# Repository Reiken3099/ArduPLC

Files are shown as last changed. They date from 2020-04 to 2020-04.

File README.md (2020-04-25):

# ArduPLC

PCB board designs developed with the purpose of being used as an alternative to the widely known PLCs in industrial environments, focusing on keeping these PCB boards as closely attached to what is currently used in the industry in terms of voltages and currents. This project does not seek in any way to replace the use of PLC devices in the industry or any related element, it is developed with the sole purpose of having a reliable and low-cost alternative to such devices, mainly for small or micro companies that require a considerable degree of automation keeping your costs and expenses as low as possible.

These boards base their operation on the ATMEL microcontrollers used in the Arduino boards, for which these can be programmed in a simple and intuitive way using the Arduino IDE software, loading the bootloader of the corresponding Arduino boards in these microcontrollers, or failing that as well They can be programmed using assembly language or C ++ and programmed with the help of a microcontroller recorder or charger. Any PCB board shown here was designed to be used with the Arduino bootloader, since by including this, you can use the program free software called "LDmicro", through which you can program ATMEL microcontrollers with the Arduino bootloader using the LADDER language or also known as the ladder language, the same language that is used to program PLC devices today.

This is a project that is currently under development, so the plates shown here have not yet been polished in terms of design and structure of their components, however, each one is fully functional and has been physically and different simulations.

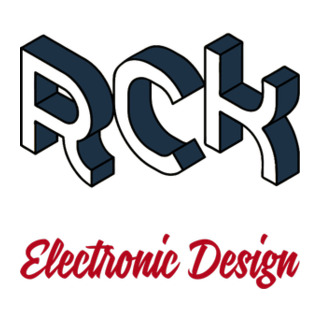
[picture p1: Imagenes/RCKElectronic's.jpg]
Logo of the organization RCKElectronic's
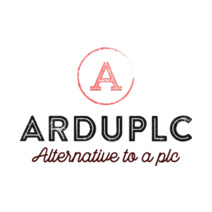
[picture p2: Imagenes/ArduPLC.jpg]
Logo of the proyect


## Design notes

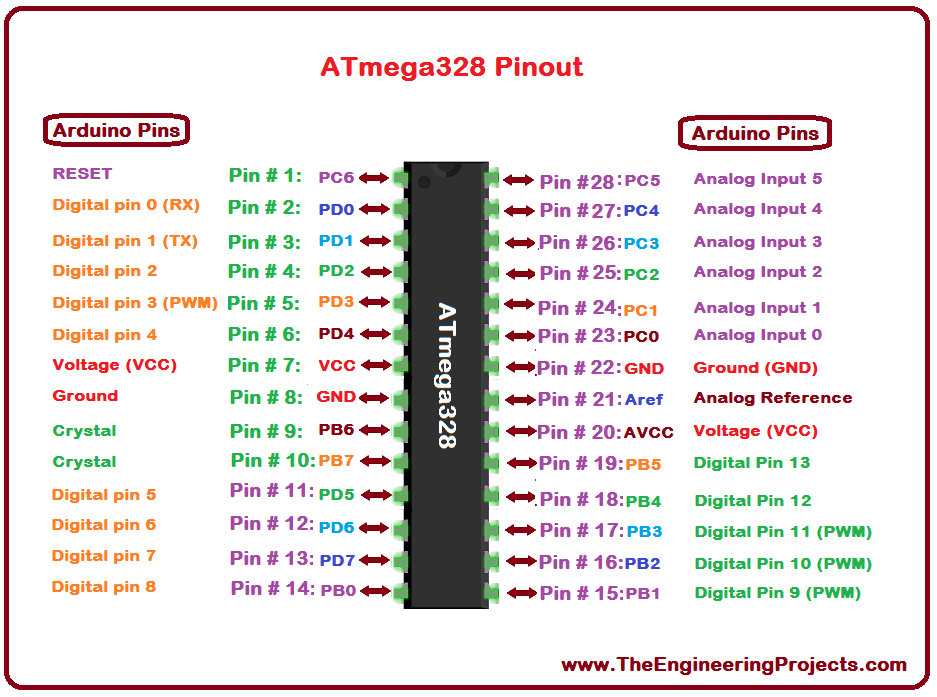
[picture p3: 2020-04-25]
ArduPLC_V1/ATmega328-Pinout.png

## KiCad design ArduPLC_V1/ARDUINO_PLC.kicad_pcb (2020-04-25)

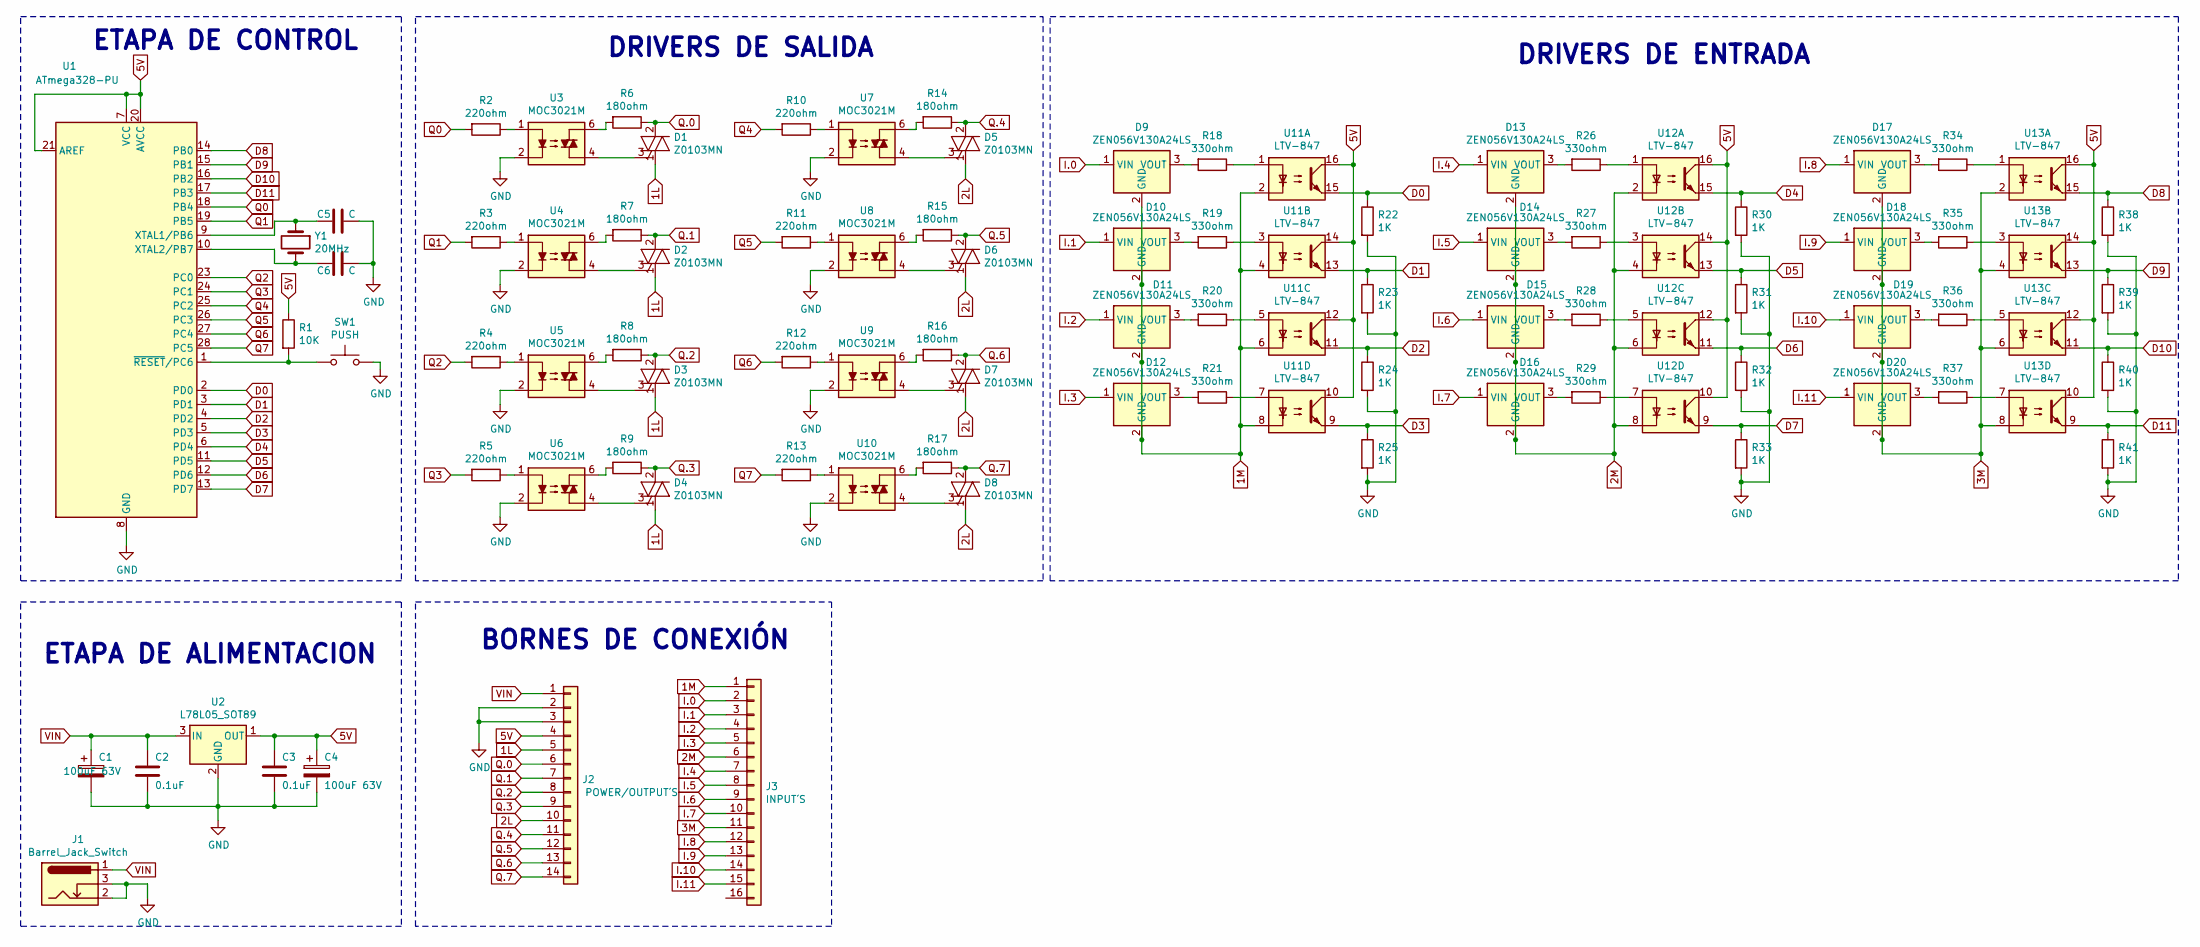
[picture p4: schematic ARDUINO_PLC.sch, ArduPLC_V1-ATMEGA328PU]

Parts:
C1, C4: 100uF 63V; CP_Radial_D8.0mm_P3.80mm
C2, C3: 0.1uF; C_Disc_D5.0mm_W2.5mm_P2.50mm
C5, C6: C; C_Disc_D5.0mm_W2.5mm_P2.50mm
D1, D2, D3, D4, D5, D6, D7, D8: Z0103MN; SOT-223
D9, D10, D11, D12, D13, D14, D15, D16, D17, D18, D19, D20: ZEN056V130A24LS; Littelfuse_PolyZen-LS
J1: Barrel_Jack_Switch; BarrelJack_Horizontal
J2: POWER/OUTPUT´S; Altech_AK300_1x14_P5.00mm_45-Degree
J3: INPUT´S; Altech_AK300_1x16_P5.00mm_45-Degree
R1: 10K; R_Axial_DIN0204_L3.6mm_D1.6mm_P1.90mm_Vertical
R2, R3, R4, R5, R10, R11, R12, R13: 220ohm; R_Axial_DIN0204_L3.6mm_D1.6mm_P1.90mm_Vertical
R6, R7, R8, R9, R14, R15, R16, R17: 180ohm; R_Axial_DIN0204_L3.6mm_D1.6mm_P1.90mm_Vertical
R18, R19, R20, R21, R26, R27, R28, R29, R34, R35, R36, R37: 330ohm; R_Axial_DIN0204_L3.6mm_D1.6mm_P1.90mm_Vertical
R22, R23, R24, R25, R30, R31, R32, R33, R38, R39, R40, R41: 1K; R_Axial_DIN0204_L3.6mm_D1.6mm_P1.90mm_Vertical
SW1: PUSH; Button_6mm
U1: ATmega328-PU; DIP-28_W7.62mm
U2: L78L05_SOT89; SOT-89-3
U3, U4, U5, U6, U7, U8, U9, U10: MOC3021M; DIP-6_W7.62mm_LongPads
U11, U12, U13: LTV-847; DIP-16_W7.62mm
Y1: 20MHz; Crystal_HC52-U_Vertical

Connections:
1L: D1.1 (A1), D2.1 (A1), D3.1 (A1), D4.1 (A1), J2.5
1M: D9.2 (GND), D10.2 (GND), D11.2 (GND), D12.2 (GND), J3.1, U11.2, U11.4, U11.6, U11.8
2L: D5.1 (A1), D6.1 (A1), D7.1 (A1), D8.1 (A1), J2.10
2M: D13.2 (GND), D14.2 (GND), D15.2 (GND), D16.2 (GND), J3.6, U12.2, U12.4, U12.6, U12.8
3M: D17.2 (GND), D18.2 (GND), D19.2 (GND), D20.2 (GND), J3.11, U13.2, U13.4, U13.6, U13.8
5V: C3.1, C4.1, J2.4, R1.1, U1.7 (VCC), U1.20 (AVCC), U1.21 (AREF), U2.1 (OUT), U11.10, U11.12, U11.14, U11.16, U12.10, U12.12, U12.14, U12.16, U13.10, U13.12, U13.14, U13.16
D0: R22.1, U1.2 (PD0), U11.15
D1: R23.1, U1.3 (PD1), U11.13
D2: R24.1, U1.4 (PD2), U11.11
D3: R25.1, U1.5 (PD3), U11.9
D4: R30.1, U1.6 (PD4), U12.15
D5: R31.1, U1.11 (PD5), U12.13
D6: R32.1, U1.12 (PD6), U12.11
D7: R33.1, U1.13 (PD7), U12.9
D8: R38.1, U1.14 (PB0), U13.15
D9: R39.1, U1.15 (PB1), U13.13
D10: R40.1, U1.16 (PB2), U13.11
D11: R41.1, U1.17 (PB3), U13.9
GND: C1.2, C2.2, C3.2, C4.2, C5.1, C6.1, J1.2, J1.3, J2.2, J2.3, R22.2, R23.2, R24.2, R25.2, R30.2, R31.2, R32.2, R33.2, R38.2, R39.2, R40.2, R41.2, SW1.2, U1.8 (GND), U1.22 (GND), U2.2 (GND), U3.2, U4.2, U5.2, U6.2, U7.2, U8.2, U9.2, U10.2
I.0: D9.1 (VIN), J3.2
I.1: D10.1 (VIN), J3.3
I.2: D11.1 (VIN), J3.4
I.3: D12.1 (VIN), J3.5
I.4: D13.1 (VIN), J3.7
I.5: D14.1 (VIN), J3.8
I.6: D15.1 (VIN), J3.9
I.7: D16.1 (VIN), J3.10
I.8: D17.1 (VIN), J3.12
I.9: D18.1 (VIN), J3.13
I.10: D19.1 (VIN), J3.14
I.11: D20.1 (VIN), J3.15
unnamed: C5.2, U1.9 (XTAL1/PB6), Y1.1
unnamed: C6.2, U1.10 (XTAL2/PB7), Y1.2
unnamed: D1.3 (G), U3.4
unnamed: D2.3 (G), U4.4
unnamed: D3.3 (G), U5.4
unnamed: D4.3 (G), U6.4
unnamed: D5.3 (G), U7.4
unnamed: D6.3 (G), U8.4
unnamed: D7.3 (G), U9.4
unnamed: D8.3 (G), U10.4
unnamed: D9.3 (VOUT), R18.2
unnamed: D10.3 (VOUT), R19.2
unnamed: D11.3 (VOUT), R20.2
unnamed: D12.3 (VOUT), R21.2
unnamed: D13.3 (VOUT), R26.2
unnamed: D14.3 (VOUT), R27.2
unnamed: D15.3 (VOUT), R28.2
unnamed: D16.3 (VOUT), R29.2
unnamed: D17.3 (VOUT), R34.2
unnamed: D18.3 (VOUT), R35.2
unnamed: D19.3 (VOUT), R36.2
unnamed: D20.3 (VOUT), R37.2
unnamed: R1.2, SW1.1, U1.1 (~RESET~/PC6)
unnamed: R2.1, U3.1
unnamed: R3.1, U4.1
unnamed: R4.1, U5.1
unnamed: R5.1, U6.1
unnamed: R6.2, U3.6
unnamed: R7.2, U4.6
unnamed: R8.2, U5.6
unnamed: R9.2, U6.6
unnamed: R10.1, U7.1
unnamed: R11.1, U8.1
unnamed: R12.1, U9.1
unnamed: R13.1, U10.1
unnamed: R14.2, U7.6
unnamed: R15.2, U8.6
unnamed: R16.2, U9.6
unnamed: R17.2, U10.6
unnamed: R18.1, U11.1
unnamed: R19.1, U11.3
unnamed: R20.1, U11.5
unnamed: R21.1, U11.7
unnamed: R26.1, U12.1
unnamed: R27.1, U12.3
unnamed: R28.1, U12.5
unnamed: R29.1, U12.7
unnamed: R34.1, U13.1
unnamed: R35.1, U13.3
unnamed: R36.1, U13.5
unnamed: R37.1, U13.7
Q0: R2.2, U1.18 (PB4)
Q1: R3.2, U1.19 (PB5)
Q2: R4.2, U1.23 (PC0)
Q3: R5.2, U1.24 (PC1)
Q4: R10.2, U1.25 (PC2)
Q5: R11.2, U1.26 (PC3)
Q6: R12.2, U1.27 (PC4)
Q7: R13.2, U1.28 (PC5)
Q.0: D1.2 (A2), D1.4 (A4), J2.6, R6.1
Q.1: D2.2 (A2), D2.4 (A4), J2.7, R7.1
Q.2: D3.2 (A2), D3.4 (A4), J2.8, R8.1
Q.3: D4.2 (A2), D4.4 (A4), J2.9, R9.1
Q.4: D5.2 (A2), D5.4 (A4), J2.11, R14.1
Q.5: D6.2 (A2), D6.4 (A4), J2.12, R15.1
Q.6: D7.2 (A2), D7.4 (A4), J2.13, R16.1
Q.7: D8.2 (A2), D8.4 (A4), J2.14, R17.1
VIN: C1.1, C2.1, J1.1, J2.1, U2.3 (IN)

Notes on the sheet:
ETAPA DE CONTROL
DRIVERS DE SALIDA
DRIVERS DE ENTRADA
ETAPA DE ALIMENTACION
BORNES DE CONEXIÓN

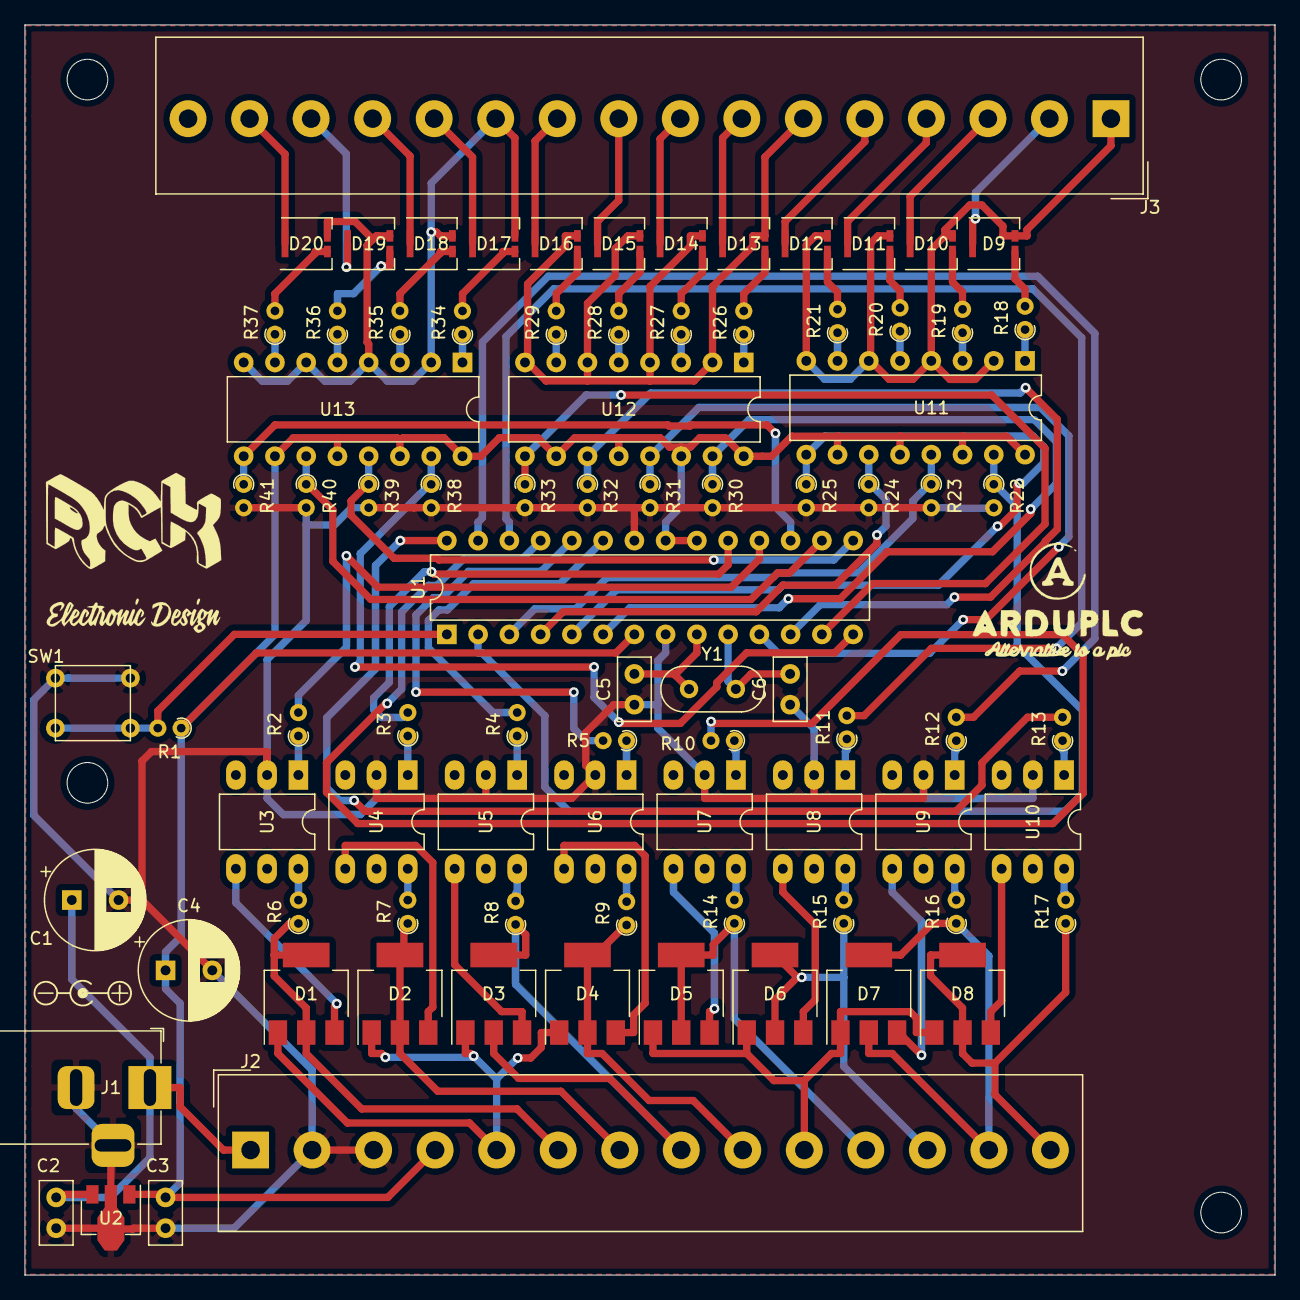
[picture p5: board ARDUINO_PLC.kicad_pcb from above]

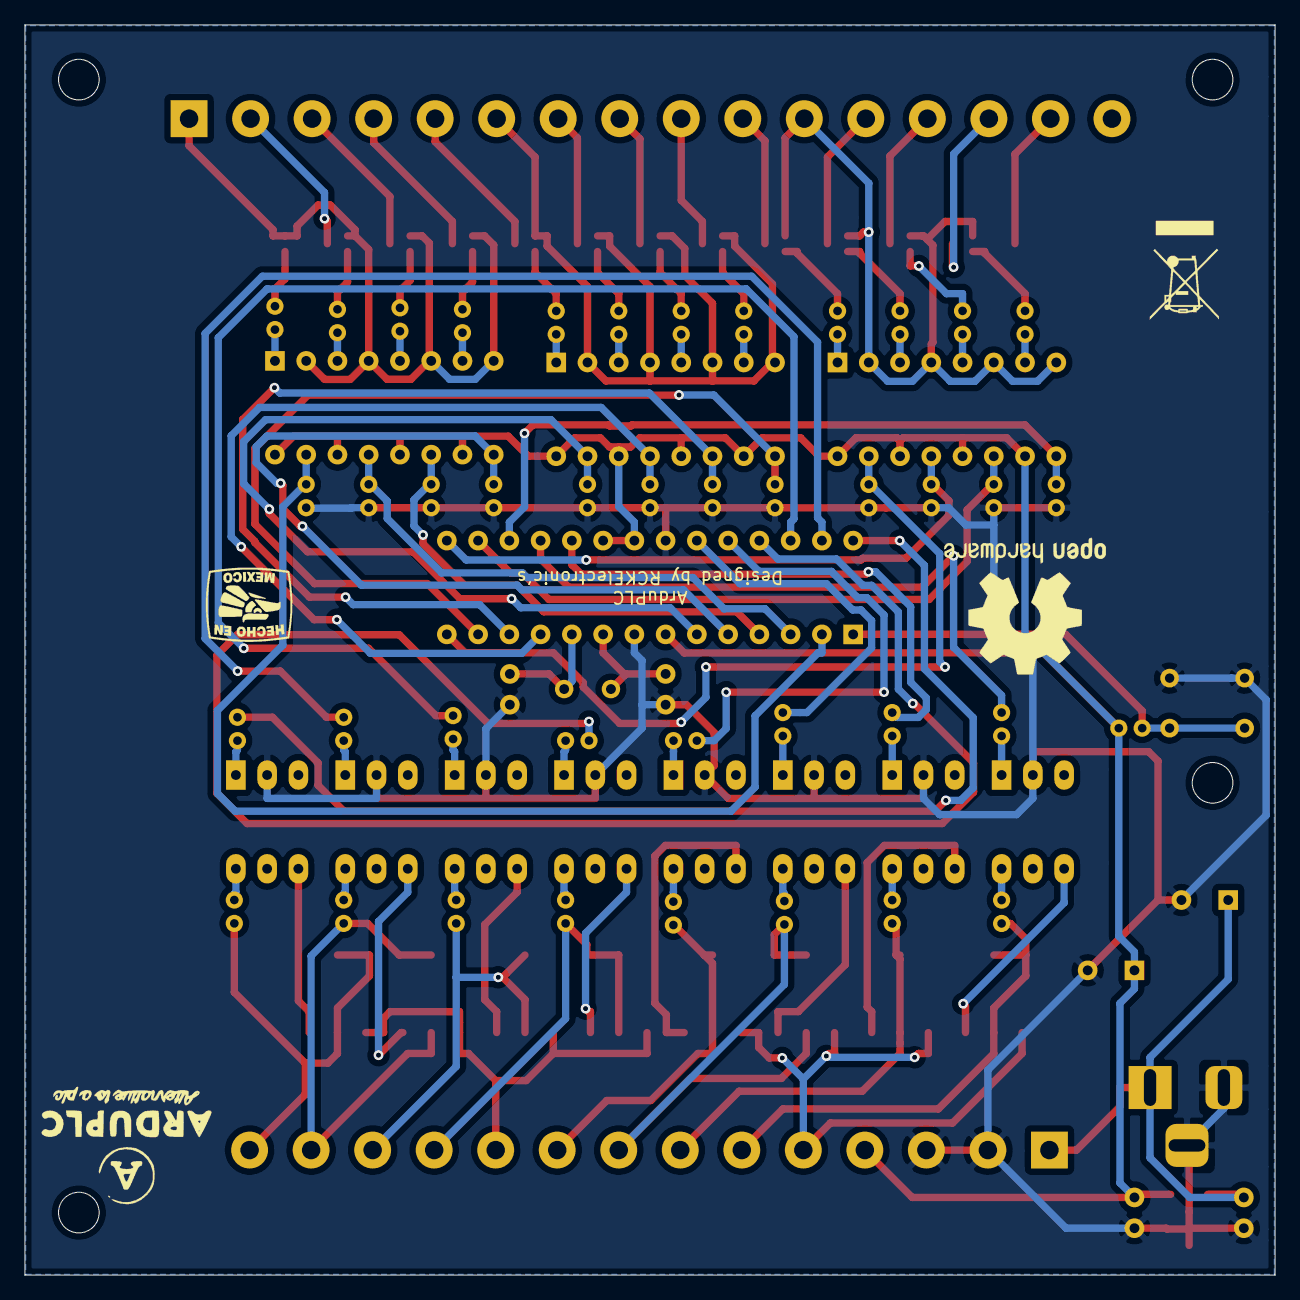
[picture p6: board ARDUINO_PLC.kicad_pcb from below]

Board: 2 copper layers, 101.6 x 101.6 mm, 89 parts (3 on the bottom side), 99 nets.

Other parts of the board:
G001: LOGO; echo_en_mexico
REF01: WEEE-Logo_5.6x8mm_SilkScreen
REF02: OSHW-Logo2_14.6x12mm_SilkScreen
REF03: Symbol_Barrel_Polarity
